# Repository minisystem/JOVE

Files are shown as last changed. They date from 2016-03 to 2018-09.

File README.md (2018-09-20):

SYSTEM80 JOVE Multimode Filter
============

Roland Jupiter 6 inspired multimode filter in 14HP Eurorack format. IR3109s replaced with LM13700 OTAs.
Selectable 24 dB low pass, bonus 2 pole 12 dB low pass, band pass and high pass modes.

Product page: http://system80.net/product/jove/<br>

Demos:<br>
https://soundcloud.com/system_80/sets/jove-demo<br>
https://soundcloud.com/system_80/sets/jove-mimoid-demo<br>
https://www.youtube.com/watch?v=VFNtQRDSUw4

EDA files generated in KiCad 4.0.2. Schematic library here: https://github.com/minisystem/MyKicadLibraries/blob/master/MySynthParts.lib
KiCad GitHub libraries required as well. :/
Front panel design by Bartek Kawula.<br>
Hardware design by minisystem: info@system80.net

PCB
===
See /Gerbers/JOVE-gerbers-1.6.zip

BOM
===
Octopart BOM: https://octopart.com/bom-tool/0BVEzM8i<br>
NOTE 1: R66 and R67 can be 0805 10R resistors or PTC fuses (see BOM for part number)<br>
NOTE 2: C1, C11, C28, C29 can be either 10 pF or 22 pF<br>

CALIBRATION
===========
Feed one of the inputs a 10 Vpp ~50 Hz square wave. In 12 dB mode with frequency and resonance knobs both at minimum (fully CCW), adjust VR5 so that the filter is fully closed. This is best done by ear using headphones. Then switch to HP mode with frequency knob at max (fully CW) and listen to ensure most of the high frequency harmonics are gone. There's a sweet spot where maximum attenuation in both modes can be achieved. The resonance trimmer is used to ensure that there is minimum resonance when the resonance knob is fully CCW. Set the frequency knob at about 12 o'clock and look for a resonance peak on the square wave in 12 dB mode using an oscilloscope. Adjust the input gain so that the output square wave is 10 Vpp. Then use VR7 to to trim away the resonance peak so that the square wave is flat. 

Acknowledgements
================
The idea to hybridize the audio input and control voltage stages from the MKS80 and SH101, respectively, comes directly from
the AMSynths AM8060: http://www.amsynthstore.co.uk/

LICENSE
=======
cc-by-nc-sa
https://creativecommons.org/licenses/by-nc-sa/4.0/<br><br>
Please note the NON-COMMERCIAL (NC) clause of the Creative Commons license.  You do not have permission to build and sell JOVE for monetary compensation.
Make one for yourself, make an extra and sell it to your friend? That's cool. Make several and sell them on eBay/ModularGrid/Tindie? No, don't do that! :)<br><br>
The NC clause isn't going to be around forever and eventually derative works for commercial use will be allowed, but currently commerical use is prohibited by the license. <br><br>
Please also note the ShareAlike (SA) clause of the license: if you create a derivative work, please ensure that it is distributed under the same license and is not used commercially.

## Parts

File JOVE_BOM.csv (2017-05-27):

Qty | Line Item | Manufacturer | MPN | Octopart URL | Schematic Reference | Internal Part Number | Description | Total Qty (@ Batch Size: 1) | SKU | SKU | Packaging | Packaging | Unit Price (@ Batch Size: 1) | Unit Price (@ Batch Size: 1) | In Stock | In Stock | MOQ | MOQ | URL | URL | Distributor [Lowest Price (Overall)] | SKU [Lowest Price (Overall)] | Packaging [Lowest Price (Overall)] | Unit Price (@ Batch Size: 1) [Lowest Price (Overall)] | Line Total [Lowest Price (Overall)] | Batch Total [Lowest Price (Overall)] | In Stock [Lowest Price (Overall)] | MOQ [Lowest Price (Overall)] | URL [Lowest Price (Overall)] | Notes
 |  |  |  |  |  |  |  |  | Digi-Key | Mouser | Digi-Key | Mouser | Digi-Key | Mouser | Digi-Key | Mouser | Digi-Key | Mouser | Digi-Key | Mouser
2 | C0603C470J5GACTU | KEMET | C0603C470J5GACTU | https://octopart.com/c0603c470j5gactu-kemet-96565 | C5,C2 | 47pF | 0603 | 2 | 399-1056-1-ND | C0603C470J5GACTU | Cut Tape |  | 0.134505 | 0.134505 | 470434 | 116632 | 1 |  | https://octopart.com/click/track?country=CA&ak=68b25f31&sig=0e3ff3a&sid=459&ppid=96565&vpid=1141107&ct=offers | https://octopart.com/click/track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 | Quest | C0603C470J5GACTU |  | 0.0403515 | 0.080703 | 0.080703 | 106700 |  | https://octopart.com/click/track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
4 | PFR5331J100J11L4BULK | KEMET | PFR5331J100J11L4BULK | https://octopart.com/pfr5331j100j11l4bulk-kemet-20374205 | C6,C7,C18,C25 | 330p FILM | 5 MM BOX CAP | 4 | 399-7719-ND | PFR5331J100J11L4BULK | Bulk |  | 0.7666784999999999 | 0.7666784999999999 | 629 | 790 | 1 |  | https://octopart.com/click/track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 | https://octopart.com/click/track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 | Digi-Key | 399-7719-ND | Bulk | 0.7666784999999999 | 3.0667139999999997 | 3.0667139999999997 | 629 | 1 | https://octopart.com/click/track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
2 | CC0603CRNPO9BN4R7 | Yageo | CC0603CRNPO9BN4R7 | https://octopart.com/cc0603crnpo9bn4r7-yageo-41162001 | C8,C3 | 4.7pF | 0603 | 2 | 311-1740-1-ND | CC0603CRNPO9BN4R7 | Cut Tape |  | 0.134505 | 0.134505 | 53904 | 2742 | 1 |  | https://octopart.com/click/track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 | https://octopart.com/click/track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 | Future Electronics | 4871679 | Cut Tape | 0.0043041600000000005 | 0.008608320000000001 | 0.008608320000000001 | 0 | 1 | https://octopart.com/click/track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
2 | C0603C330J5GACTU | KEMET | C0603C330J5GACTU | https://octopart.com/c0603c330j5gactu-kemet-87666 | C9,C4 | 33pF | 0603 | 2 | 399-1055-1-ND | C0603C330J5GACTU | Cut Tape |  | 0.134505 | 0.134505 | 159937 | 66424 | 1 |  | https://octopart.com/click/track?country=CA&ak=68b25f31&sig=03ed878&sid=459&ppid=87666&vpid=1868169&ct=offers | https://octopart.com/click/track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 | Quest | C0603C330J5GACTU |  | 0.04438665000000001 | 0.08877330000000001 | 0.08877330000000001 | 87384 |  | https://octopart.com/click/track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
1 | UUQ1E100MCL1GB | Nichicon | UUQ1E100MCL1GB | https://octopart.com/uuq1e100mcl1gb-nichicon-19038212 | C10 | 10μF | 5mm x 5.3mm | 1 | 493-3202-1-ND | UUQ1E100MCL1GB | Cut Tape |  | 0.6590745 | 0.6052725000000001 | 436 | 1420 | 1 |  | https://octopart.com/click/track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 | https://octopart.com/click/track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 | Arrow | UUQ1E100MCL1GB**MULT1 | Cut Tape | 0.44184892500000006 | 0.44184892500000006 | 0.44184892500000006 | 190 | 1 | https://octopart.com/click/track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
4 | C0603C100J5GACTU | KEMET | C0603C100J5GACTU | https://octopart.com/c0603c100j5gactu-kemet-138281 | C11,C1,C28,C29 | 22pF | 0603 | 4 | 399-1049-1-ND | C0603C100J5GACTU | Cut Tape |  | 0.134505 | 0.134505 | 684636 | 136314 | 1 |  | https://octopart.com/click/track?country=CA&ak=68b25f31&sig=0221e5b&sid=459&ppid=138281&vpid=2013189&ct=offers | https://octopart.com/click/track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 | Quest | C0603C100J5GACTU |  | 0.04438665000000001 | 0.17754660000000003 | 0.17754660000000003 | 90266 |  | https://octopart.com/click/track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
2 | GRM188R61E105KA12D | Murata | GRM188R61E105KA12D | https://octopart.com/grm188r61e105ka12d-murata-197449 | C22,C21 | 1μ | 0603 | 2 | 490-3897-1-ND | GRM188R61E105KA12D | Cut Tape |  | 0.134505 | 0.14795550000000002 | 2332690 | 474291 | 1 |  | https://octopart.com/click/track?country=CA&ak=68b25f31&sig=0dbf803&sid=459&ppid=197449&vpid=1620758&ct=offers | https://octopart.com/click/track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 | Arrow | GRM188R61E105KA12D**MULT |  | 0.058375170000000004 | 0.11675034000000001 | 0.11675034000000001 | 104 | 1 | https://octopart.com/click/track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
2 | EEE-1EA100SR | Panasonic | EEE1EA100SR | https://octopart.com/eee1ea100sr-panasonic-55403445 | C23,C24 | 10μF | 5mm x 5.8mm | 2 | PCE3894CT-ND | EEE1EA100SR | Cut Tape |  | 0.44386650000000005 | 0.48421800000000004 | 119898 | 4880 | 1 |  | https://octopart.com/click/track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 | https://octopart.com/click/track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 | Allied Electronics | 70257957 | Bulk | 0.10087875 | 0.2017575 | 0.2017575 | 1445 | 1 | https://octopart.com/click/track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
10 | C0603C104M5RACTU | KEMET | C0603C104M5RACTU | https://octopart.com/c0603c104m5ractu-kemet-11855687 | C27,C20,C19,C17,C16,C15,C14,C13,C12,C26 | 100n | 0603 | 10 | 399-7845-1-ND | C0603C104M5RACTU | Cut Tape |  | 0.039006450000000005 | 0.021520800000000003 | 2577395 | 477739 | 1 |  | https://octopart.com/click/track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 | https://octopart.com/click/track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 | Mouser | C0603C104M5RACTU |  | 0.021520800000000003 | 0.21520800000000004 | 0.21520800000000004 | 477739 |  | https://octopart.com/click/track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
4 | WP424SRDT | Kingbright | WP424SRDT | https://octopart.com/wp424srdt-kingbright-5355810 | D1,D2,D3,D4 | LED | 3 MM LED | 4 | 754-1717-ND | WP424SRDT | Bulk |  | 0.6590745 | 0.34971300000000005 | 9014 | 1900 | 1 |  | https://octopart.com/click/track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 | https://octopart.com/click/track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 | Mouser | WP424SRDT |  | 0.34971300000000005 | 1.3988520000000002 | 1.3988520000000002 | 1900 |  | https://octopart.com/click/track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
2 | S1BB-13-F | Diodes Inc. | S1BB-13-F | https://octopart.com/s1bb-13-f-diodes+inc.-333220 | D8,D9 | S1BB | SMB | 2 | S1BB-FDICT-ND | S1BB-13-F | Cut Tape |  | 0.4976685 | 0.564921 | 32572 | 4740 | 1 |  | https://octopart.com/click/track?country=CA&ak=68b25f31&sig=04f214c&sid=459&ppid=333220&vpid=1137864&ct=offers | https://octopart.com/click/track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 | Freelance Electronics | S1BB-13-F |  | 0.12105450000000001 | 0.24210900000000002 | 0.24210900000000002 | 3000 |  | https://octopart.com/click/track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
4 | 1N914BWS | Fairchild Semiconductor | 1N914BWS | https://octopart.com/1n914bws-fairchild+semiconductor-7850921 | D10,D7,D6,D5 | 1N914 | SOD323 | 4 | 1N914BWSCT-ND | 1N914BWS | Cut Tape |  | 0.18830700000000003 | 0.17485650000000003 | 253227 | 61488 | 1 |  | https://octopart.com/click/track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 | https://octopart.com/click/track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 | Rochester Electronics | 1N914BWS |  | 0.026901 | 0.107604 | 0.107604 | 70048 |  | https://octopart.com/click/track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
6 | PJ301BM |  |  |  | J1,J2,J3,J4,J5,J6 | WQP-PJ301BM | 3.5 MM JACK | 6
2 | BCM857BS-7-F | Diodes Inc. | BCM857BS-7-F | https://octopart.com/bcm857bs-7-f-diodes+inc.-67250368 | Q2,Q1 | BCM857BS | SOT323-6 | 2 | BCM857BS-7-FDICT-ND | BCM857BS-7-F | Cut Tape |  | 0.44386650000000005 | 0.403515 | 950 | 2760 | 1 |  | https://octopart.com/click/track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 | https://octopart.com/click/track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 | Mouser | BCM857BS-7-F |  | 0.403515 | 0.80703 | 0.80703 | 2760 |  | https://octopart.com/click/track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
4 | MMBFJ112 | Fairchild Semiconductor | MMBFJ112 | https://octopart.com/mmbfj112-fairchild+semiconductor-13412317 | Q6,Q5,Q4,Q3 | J112 | SOT23 | 4 | MMBFJ112CT-ND |  | Cut Tape |  | 0.618723 |  | 14344 |  | 1 |  | https://octopart.com/click/track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 |  | Future Electronics | 3286895 | Cut Tape | 0.1129842 | 0.4519368 | 0.4519368 | 0 | 1 | https://octopart.com/click/track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
4 | RC0603FR-0710KL | Yageo | RC0603FR-0710KL | https://octopart.com/rc0603fr-0710kl-yageo-40025538 | R1,R49,R70,R71 | 10K | 0603 | 4 | 311-10.0KHRCT-ND | RC0603FR-0710KL | Cut Tape |  | 0.134505 | 0.134505 | 17944628 | 1019470 | 1 |  | https://octopart.com/click/track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 | https://octopart.com/click/track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 | Area51 | RC0603FR-0710KL |  | 0.002017575 | 0.0080703 | 0.0080703 | 5385 |  | https://octopart.com/click/track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
2 | RC0603FR-07200KL | Yageo | RC0603FR-07200KL | https://octopart.com/rc0603fr-07200kl-yageo-1190520 | R5,R6 | 200K | 0603 | 2 | 311-200KHRCT-ND | RC0603FR-07200KL | Cut Tape |  | 0.134505 | 0.134505 | 1134443 | 108759 | 1 |  | https://octopart.com/click/track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 | https://octopart.com/click/track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 | Freelance Electronics | RC0603FR-07200KL |  | 0.0134505 | 0.026901 | 0.026901 | 0 |  | https://octopart.com/click/track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
1 | RC0603FR-07110KL | Yageo | RC0603FR-07110KL | https://octopart.com/rc0603fr-07110kl-yageo-1180242 | R9 | 110K | 0603 | 1 | 311-110KHRCT-ND | RC0603FR-07110KL | Cut Tape |  | 0.134505 | 0.134505 | 508755 | 129823 | 1 |  | https://octopart.com/click/track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 | https://octopart.com/click/track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 | Quest | RC0603FR-07110KL |  | 0.018158175000000002 | 0.018158175000000002 | 0.018158175000000002 | 4905 |  | https://octopart.com/click/track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
1 | RC0603FR-07680KL | Yageo | RC0603FR-07680KL | https://octopart.com/rc0603fr-07680kl-yageo-55458494 | R10 | 680K | 0603 | 1 | 311-680KHRCT-ND | RC0603FR-07680KL | Cut Tape |  | 0.134505 | 0.134505 | 235274 | 34193 | 1 |  | https://octopart.com/click/track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 | https://octopart.com/click/track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 | Newark | 66R2539 |  | 0.008 | 0.008 | 0.008 | 0 |  | https://octopart.com/click/track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
1 | RC0603FR-071ML | Yageo | RC0603FR-071ML | https://octopart.com/rc0603fr-071ml-yageo-1168402 | R11 | 1M | 0603 | 1 | 311-1.00MHRCT-ND | RC0603FR-071ML | Cut Tape |  | 0.134505 | 0.134505 | 2247161 | 602974 | 1 |  | https://octopart.com/click/track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 | https://octopart.com/click/track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 | Quest | RC0603FR-071ML |  | 0.018158175000000002 | 0.018158175000000002 | 0.018158175000000002 | 73887 |  | https://octopart.com/click/track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
2 | RC0603FR-071KL | Yageo | RC0603FR-071KL | https://octopart.com/rc0603fr-071kl-yageo-55402882 | R12,R54 | 1K | 0603 | 2 | 311-1.00KHRCT-ND | RC0603FR-071KL | Cut Tape |  | 0.134505 | 0.134505 | 7245403 | 1109725 | 1 |  | https://octopart.com/click/track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 | https://octopart.com/click/track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 | Area51 | RC0603FR-071KL |  | 0.0026901000000000004 | 0.005380200000000001 | 0.005380200000000001 | 15094 |  | https://octopart.com/click/track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
4 | RC0603FR-071KL | Yageo | RC0603FR-071KL | https://octopart.com/rc0603fr-071kl-yageo-55402882 | R13,R14,R18,R50 | 47K | 0603 | 4 | 311-1.00KHRCT-ND | RC0603FR-071KL | Cut Tape |  | 0.134505 | 0.134505 | 7245403 | 1109725 | 1 |  | https://octopart.com/click/track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 | https://octopart.com/click/track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 | Area51 | RC0603FR-071KL |  | 0.0026901000000000004 | 0.010760400000000002 | 0.010760400000000002 | 15094 |  | https://octopart.com/click/track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
1 | RC0603FR-07150KL | Yageo | RC0603FR-07150KL | https://octopart.com/rc0603fr-07150kl-yageo-40301068 | R15 | 150K | 0603 | 1 | 311-150KHRCT-ND | RC0603FR-07150KL | Cut Tape |  | 0.134505 | 0.134505 | 397717 | 170321 | 1 |  | https://octopart.com/click/track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 | https://octopart.com/click/track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 | Quest | RC0603FR-07150KL |  | 0.0242109 | 0.0242109 | 0.0242109 | 27642 |  | https://octopart.com/click/track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
1 | RC0603FR-074K7L | Yageo | RC0603FR-074K7L | https://octopart.com/rc0603fr-074k7l-yageo-55402884 | R16 | 4.7K | 0603 | 1 | 311-4.70KHRCT-ND | RC0603FR-074K7L | Cut Tape |  | 0.134505 | 0.134505 | 3399606 | 646715 | 1 |  | https://octopart.com/click/track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 | https://octopart.com/click/track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 | Area51 | RC0603FR-074K7L |  | 0.0029591100000000005 | 0.0029591100000000005 | 0.0029591100000000005 | 14451 |  | https://octopart.com/click/track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
1 | RC0603FR-105K6L | Yageo | RC0603FR-105K6L | https://octopart.com/rc0603fr-105k6l-yageo-16255932 | R17 | 5.6K | 0603 | 1 |  | RC0603FR-105K6L |  |  |  | 0.134505 |  | 68551 |  |  |  | https://octopart.com/click/track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 | Mouser | RC0603FR-105K6L |  | 0.134505 | 0.134505 | 0.134505 | 68551 |  | https://octopart.com/click/track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
1 | ABNTC-0805-103J-3950F-T | Abracon | ABNTC-0805-103J-3950F-T | https://octopart.com/abntc-0805-103j-3950f-t-abracon-29811145 | R19 | 10K NTC | 0805 | 1 | 535-12852-1-ND |  | Cut Tape |  | 0.36316350000000003 |  | 2579 |  | 1 |  | https://octopart.com/click/track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 |  | Digi-Key | 535-12852-1-ND | Cut Tape | 0.36316350000000003 | 0.36316350000000003 | 0.36316350000000003 | 2579 | 1 | https://octopart.com/click/track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
2 | RC0603FR-071K5L | Yageo | RC0603FR-071K5L | https://octopart.com/rc0603fr-071k5l-yageo-55458478 | R20,R27 | 1.5K | 0603 | 2 | 311-1.50KHRCT-ND | RC0603FR-071K5L | Cut Tape |  | 0.134505 | 0.134505 | 454711 | 216796 | 1 |  | https://octopart.com/click/track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 | https://octopart.com/click/track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 | Area51 | RC0603FR-071K5L |  | 0.0026901000000000004 | 0.005380200000000001 | 0.005380200000000001 | 2299 |  | https://octopart.com/click/track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
2 | RC0603FR-071M5L | Yageo | RC0603FR-071M5L | https://octopart.com/rc0603fr-071m5l-yageo-40315640 | R21,R28 | 1.5M | 0603 | 2 | 311-1.50MHRCT-ND | RC0603FR-071M5L | Cut Tape |  | 0.134505 | 0.134505 | 306867 | 0 | 1 |  | https://octopart.com/click/track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 | https://octopart.com/click/track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 | Future Electronics | 6843296 | Cut Tape | 0.07397775000000001 | 0.14795550000000002 | 0.14795550000000002 | 0 | 1 | https://octopart.com/click/track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
1 | RC0603FR-078K2L | Yageo | RC0603FR-078K2L | https://octopart.com/rc0603fr-078k2l-yageo-40301092 | R22 | 8.2K | 0603 | 1 | 311-8.20KHRCT-ND | RC0603FR-078K2L | Cut Tape |  | 0.134505 | 0.134505 | 668000 | 60464 | 1 |  | https://octopart.com/click/track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 | https://octopart.com/click/track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 | Quest | RC0603FR-078K2L |  | 0.018158175000000002 | 0.018158175000000002 | 0.018158175000000002 | 53805 |  | https://octopart.com/click/track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
1 | RC0603FR-071K8L | Yageo | RC0603FR-071K8L | https://octopart.com/rc0603fr-071k8l-yageo-40952851 | R23 | 1.8K | 0603 | 1 | 311-1.80KHRCT-ND | RC0603FR-071K8L | Cut Tape |  | 0.134505 | 0.134505 | 435112 | 113375 | 1 |  | https://octopart.com/click/track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 | https://octopart.com/click/track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 | Quest | RC0603FR-071K8L |  | 0.018158175000000002 | 0.018158175000000002 | 0.018158175000000002 | 3171 |  | https://octopart.com/click/track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
1 | RC0603FR-07820RL | Yageo | RC0603FR-07820RL | https://octopart.com/rc0603fr-07820rl-yageo-41204300 | R25 | 820 | 0603 | 1 | 311-820HRCT-ND | RC0603FR-07820RL | Cut Tape |  | 0.134505 | 0.134505 | 216811 | 16295 | 1 |  | https://octopart.com/click/track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 | https://octopart.com/click/track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 | Future Electronics | 8386369 | Cut Tape | 0.07397775000000001 | 0.07397775000000001 | 0.07397775000000001 | 2703 | 1 | https://octopart.com/click/track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
6 | RC0603FR-0768KL | Yageo | RC0603FR-0768KL | https://octopart.com/rc0603fr-0768kl-yageo-41204191 | R29,R35,R37,R52,R60,R63 | 68K | 0603 | 6 | 311-68.0KHRCT-ND | RC0603FR-0768KL | Cut Tape |  | 0.134505 | 0.134505 | 613756 | 73519 | 1 |  | https://octopart.com/click/track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 | https://octopart.com/click/track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 | ExcessParts.Net | RC0603FR-0768KL |  | 0.0134505 | 0.080703 | 0.080703 | 4967 |  | https://octopart.com/click/track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
6 | RC0603FR-07560RL | Yageo | RC0603FR-07560RL | https://octopart.com/rc0603fr-07560rl-yageo-1265587 | R30,R36,R38,R53,R62,R65 | 560 | 0603 | 6 | 311-560HRCT-ND | RC0603FR-07560RL | Cut Tape |  | 0.134505 | 0.134505 | 1093994 | 48486 | 1 |  | https://octopart.com/click/track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 | https://octopart.com/click/track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 | Quest | RC0603FR-07560RL |  | 0.030263625000000002 | 0.18158175000000001 | 0.18158175000000001 | 4730 |  | https://octopart.com/click/track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
6 | RC0603FR-0718KL | Yageo | RC0603FR-0718KL | https://octopart.com/rc0603fr-0718kl-yageo-40952836 | R31,R32,R39,R55,R56,R68 | 18K | 0603 | 6 | 311-18.0KHRCT-ND | RC0603FR-0718KL | Cut Tape |  | 0.134505 | 0.134505 | 574517 | 68400 | 1 |  | https://octopart.com/click/track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 | https://octopart.com/click/track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 | Future Electronics | 7908486 | Cut Tape | 0.07397775000000001 | 0.44386650000000005 | 0.44386650000000005 | 0 | 1 | https://octopart.com/click/track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
7 | RC0603FR-0733KL | Yageo | RC0603FR-0733KL | https://octopart.com/rc0603fr-0733kl-yageo-40254901 | R33,R34,R40,R46,R57,R58,R69 | 33K | 0603 | 7 | 311-33.0KHRCT-ND | RC0603FR-0733KL | Cut Tape |  | 0.134505 | 0.134505 | 603894 | 372069 | 1 |  | https://octopart.com/click/track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 | https://octopart.com/click/track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 | Newark | 68R0084 | Cut Tape | 0.002 | 0.014 | 0.014 | 3250 | 1 | https://octopart.com/click/track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
1 | RC0603FR-073K3L | Yageo | RC0603FR-073K3L | https://octopart.com/rc0603fr-073k3l-yageo-40011875 | R41 | 3.3K | 0603 | 1 | 311-3.30KHRCT-ND | RC0603FR-073K3L | Cut Tape |  | 0.134505 | 0.134505 | 1860756 | 206098 | 1 |  | https://octopart.com/click/track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 | https://octopart.com/click/track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 | Quest | RC0603FR-073K3L |  | 0.0242109 | 0.0242109 | 0.0242109 | 29387 |  | https://octopart.com/click/track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
2 | RC0603FR-0756KL | Yageo | RC0603FR-0756KL | https://octopart.com/rc0603fr-0756kl-yageo-41455254 | R42,R43 | 56K | 0603 | 2 | 311-56KHRCT-ND | RC0603FR-0756KL | Cut Tape |  | 0.134505 | 0.134505 | 434712 | 130124 | 1 |  | https://octopart.com/click/track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 | https://octopart.com/click/track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 | Digi-Key | 311-56KHRCT-ND | Cut Tape | 0.134505 | 0.26901 | 0.26901 | 434712 | 1 | https://octopart.com/click/track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
1 | RC0603FR-07330KL | Yageo | RC0603FR-07330KL | https://octopart.com/rc0603fr-07330kl-yageo-40952887 | R51 | 330K | 0603 | 1 | 311-330KHRCT-ND | RC0603FR-07330KL | Cut Tape |  | 0.134505 | 0.134505 | 232278 | 41774 | 1 |  | https://octopart.com/click/track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 | https://octopart.com/click/track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 | ExcessParts.Net | RC0603FR-07330KL |  | 0.0134505 | 0.0134505 | 0.0134505 | 4979 |  | https://octopart.com/click/track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
2 | RC0603FR-07330RL | Yageo | RC0603FR-07330RL | https://octopart.com/rc0603fr-07330rl-yageo-40301083 | R59,R64 | 330 | 0603 | 2 | 311-330HRCT-ND | RC0603FR-07330RL | Cut Tape |  | 0.134505 | 0.134505 | 1445260 | 68556 | 1 |  | https://octopart.com/click/track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 | https://octopart.com/click/track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 | Quest | RC0603FR-07330RL |  | 0.0242109 | 0.0484218 | 0.0484218 | 21201 |  | https://octopart.com/click/track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
2 | ERJ-8GEYJ100V | Panasonic | ERJ-8GEYJ100V | https://octopart.com/erj-8geyj100v-panasonic-55423812 | R67,R66 | 10 | 0805 | 2 | P10ECT-ND | ERJ-8GEYJ100V | Cut Tape |  | 0.134505 | 0.134505 | 490916 | 28966 | 1 |  | https://octopart.com/click/track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 | https://octopart.com/click/track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 | Allied Electronics | 70266197 | Bulk | 0.00403515 | 0.0080703 | 0.0080703 | 143780 | 1 | https://octopart.com/click/track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
1 | RC0603FR-07270KL | Yageo | RC0603FR-07270KL | https://octopart.com/rc0603fr-07270kl-yageo-40301078 | R72 | 270K | 0603 | 1 | 311-270KHRCT-ND | RC0603FR-07270KL | Cut Tape |  | 0.134505 | 0.134505 | 664816 | 81941 | 1 |  | https://octopart.com/click/track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 | https://octopart.com/click/track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 | Area51 | RC0603FR-07270KL |  | 0.003362625 | 0.003362625 | 0.003362625 | 9615 |  | https://octopart.com/click/track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
19 | RC0603FR-07100KL | Yageo | RC0603FR-07100KL | https://octopart.com/rc0603fr-07100kl-yageo-40946036 | R76,R2,R3,R4,R7,R8,R24,R26,R44,R45,R47,R48,R61,R73,R74,R75,R77,R78 | 100K | 0603 | 19 | 311-100KHRCT-ND | RC0603FR-07100KL | Cut Tape |  | 0.018830700000000002 | 0.0134505 | 4853686 | 967388 | 1 |  | https://octopart.com/click/track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 | https://octopart.com/click/track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 | Farnell | 9238727 | Cut Tape | 0.012229073880094352 | 0.23235240372179267 | 0.23235240372179267 | 129026 | 10 | https://octopart.com/click/track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
1 | KS-01Q-01 | E-Switch | KS-01Q-01 | https://octopart.com/ks-01q-01-e-switch-18183226 | SW1 | SWITCH | KS-01Q | 1 | EG4791-ND | KS-01Q-01 | Bulk |  | 0.7128765 | 0.6994260000000001 | 7502 | 3773 | 1 |  | https://octopart.com/click/track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 | https://octopart.com/click/track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 | Straight Road Electronics | KS-01Q-01 |  | 0.5245695 | 0.5245695 | 0.5245695 | 0 |  | https://octopart.com/click/track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
4 | TL072CPWR | Texas Instruments | TL072CPWR | https://octopart.com/tl072cpwr-texas+instruments-409969 | U1,U2,U3,U4 | TL072 | TSSOP8 | 4 | 296-7193-1-ND | TL072CPWR | Cut Tape |  | 0.8339310000000001 | 0.7935795 | 13222 | 8545 | 1 |  | https://octopart.com/click/track?country=CA&ak=68b25f31&sig=07aa9a4&sid=459&ppid=409969&vpid=1542372&ct=offers | https://octopart.com/click/track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 | Rochester Electronics | TL072CPWR |  | 0.3900645 | 1.560258 | 1.560258 | 4890 |  | https://octopart.com/click/track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

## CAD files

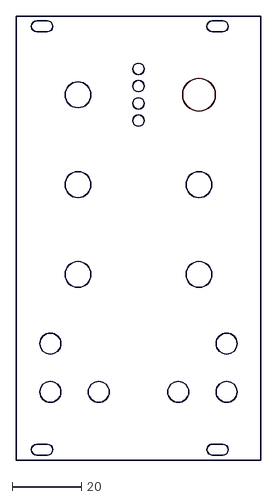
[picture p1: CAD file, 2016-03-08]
Panel/Jove_panel_drill_holes.dxf
70.8 x 128.5

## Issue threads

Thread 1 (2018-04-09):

Value for c1 c11 c28 and c29

pandereteiro, 2018-04-09:
Schematics call for 22pF

BOM (row #8) calls for 10pF https://github.com/minisystem/JOVE/blob/master/JOVE_BOM.csv
even pointing to this in Octopart: https://octopart.com/c0603c100j5gactu-kemet-138281

Which is the correct value for those capacitors?

fabianunterstell, 2020-07-25:
from the README.md:
NOTE 2: C1, C11, C28, C29 can be either 10 pF or 22 pF

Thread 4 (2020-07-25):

resistors r67, r66 with wrong smd package size in the BOM

fabianunterstell, 2020-07-25:
in the BOM the resistors r67, r66 have package size 0805 in the description field and that size fits on the pcb as well.

the recommended resistor is a panasonic ERJ-8GEYJ100V which has package size 1206 as can be seen in the datasheet here:
https://www.mouser.de/datasheet/2/315/AOA0000C301-1488782.pdf

the correct sized resistor would be the panasonic ERJ-6GEYJ100V

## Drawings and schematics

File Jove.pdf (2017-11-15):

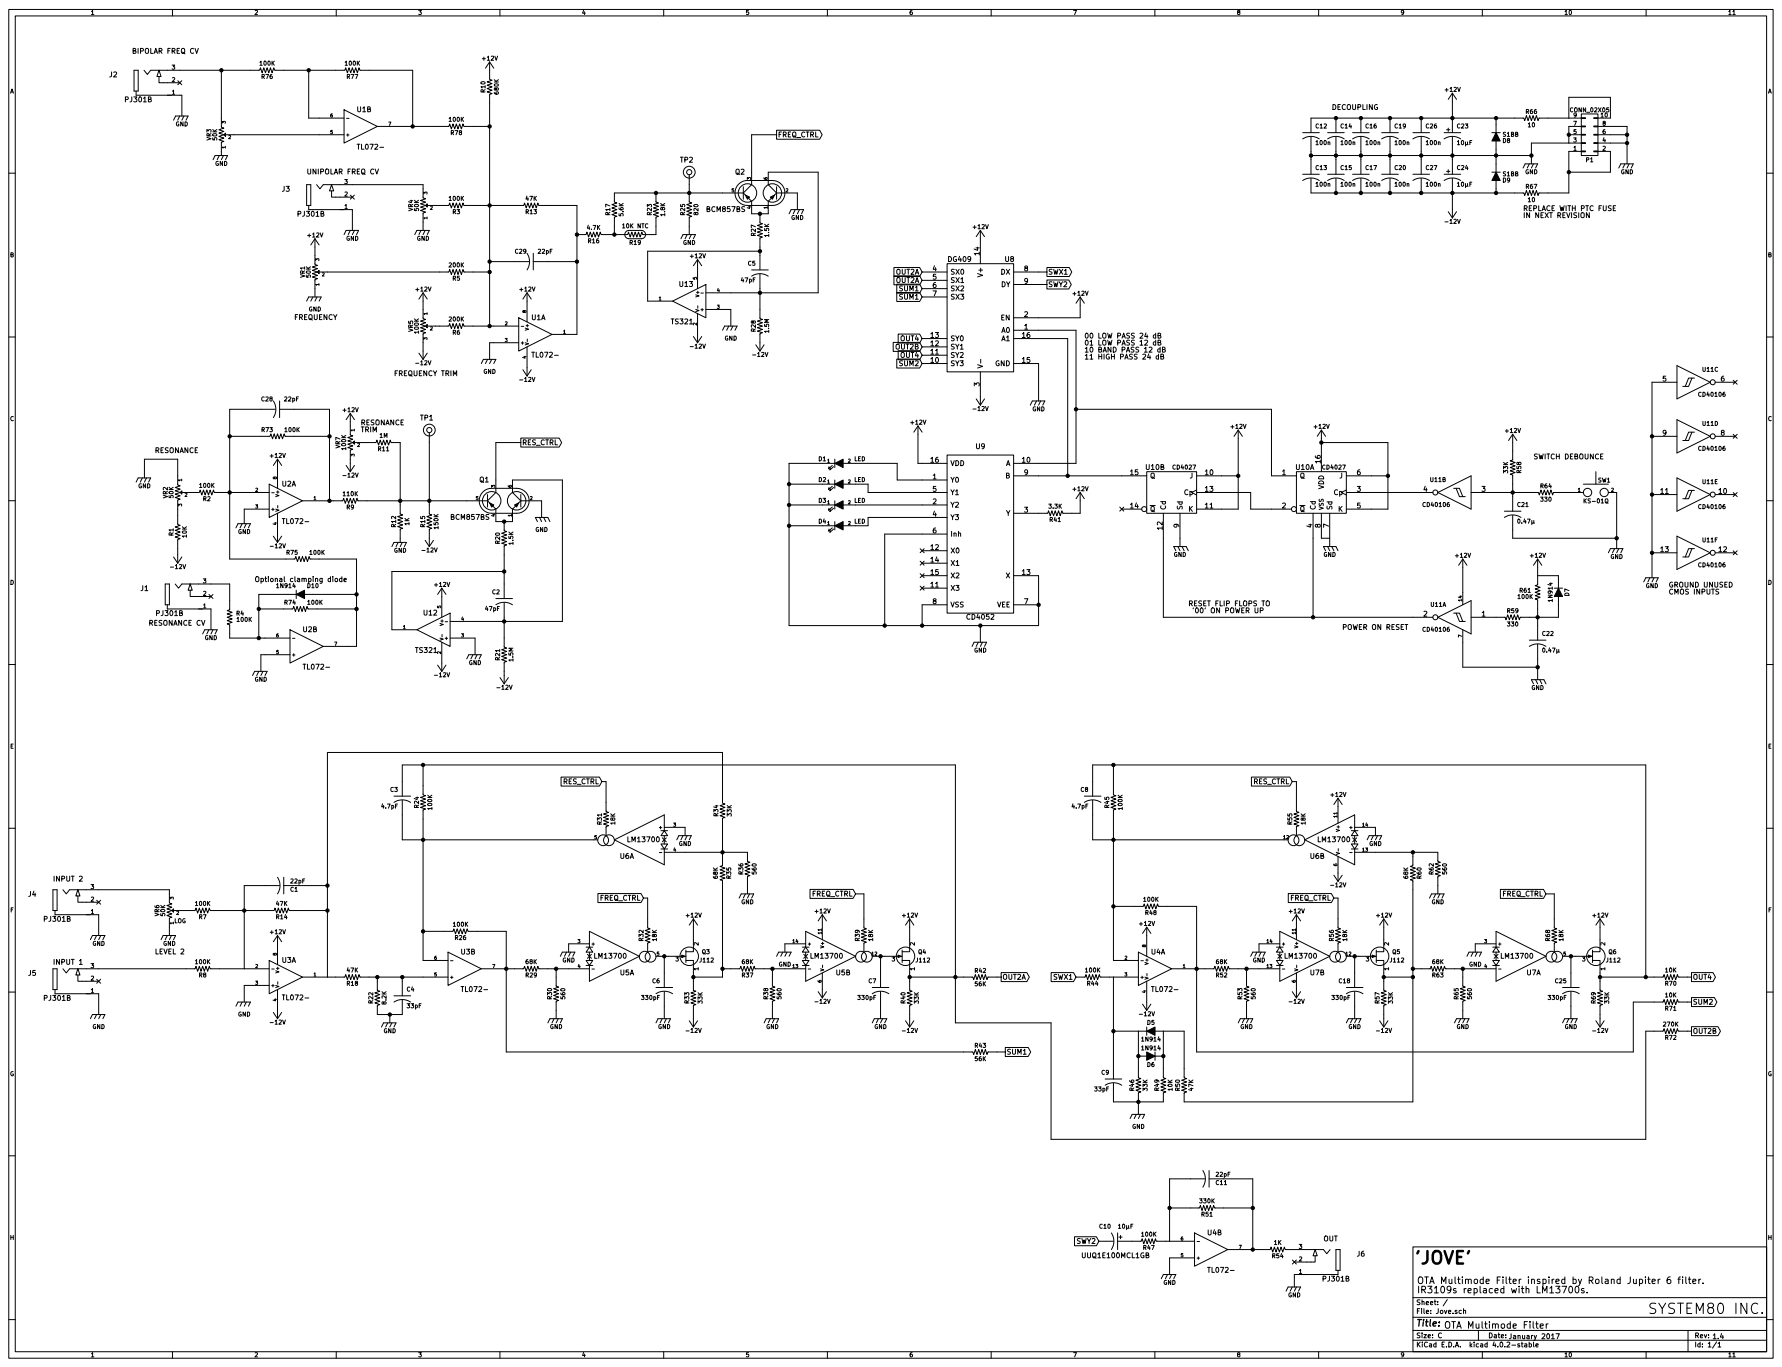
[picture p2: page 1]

REPLACE WITH PTC FUSE
IN NEXT REVISION

CMOS INPUTS RESET FLIP FLOPS TO

OTA Multimode Filter inspired by Roland Jupiter 6 filter.

Id: 1/1 Title: File: Jove.sch Sheet: /

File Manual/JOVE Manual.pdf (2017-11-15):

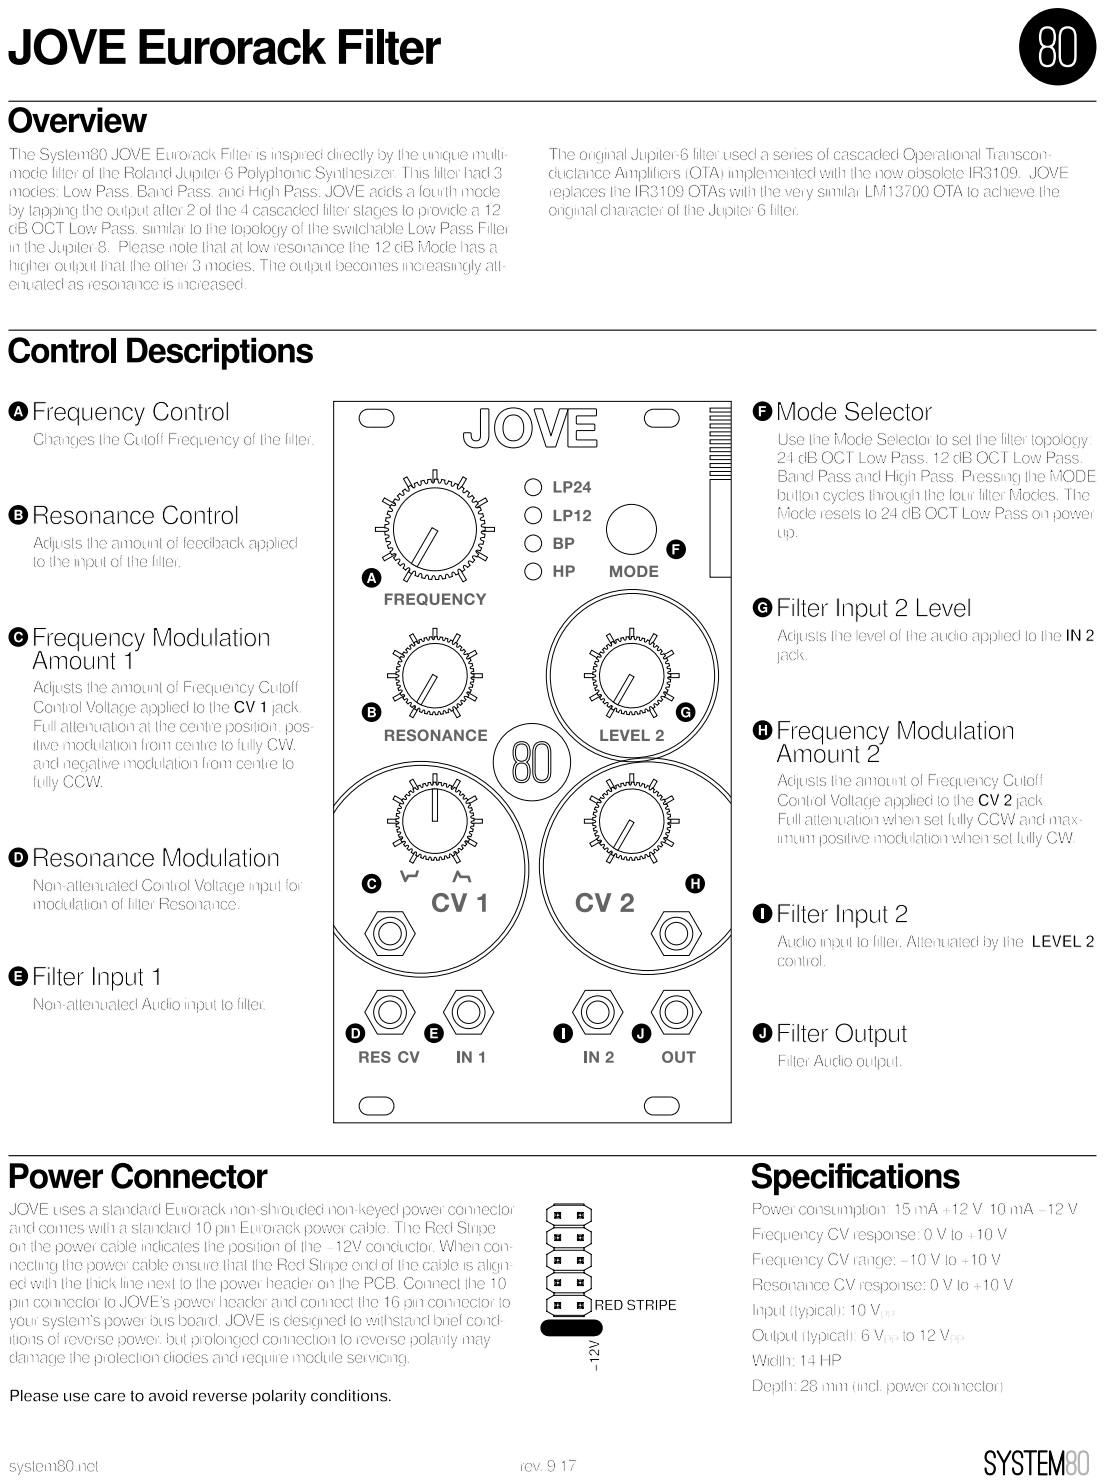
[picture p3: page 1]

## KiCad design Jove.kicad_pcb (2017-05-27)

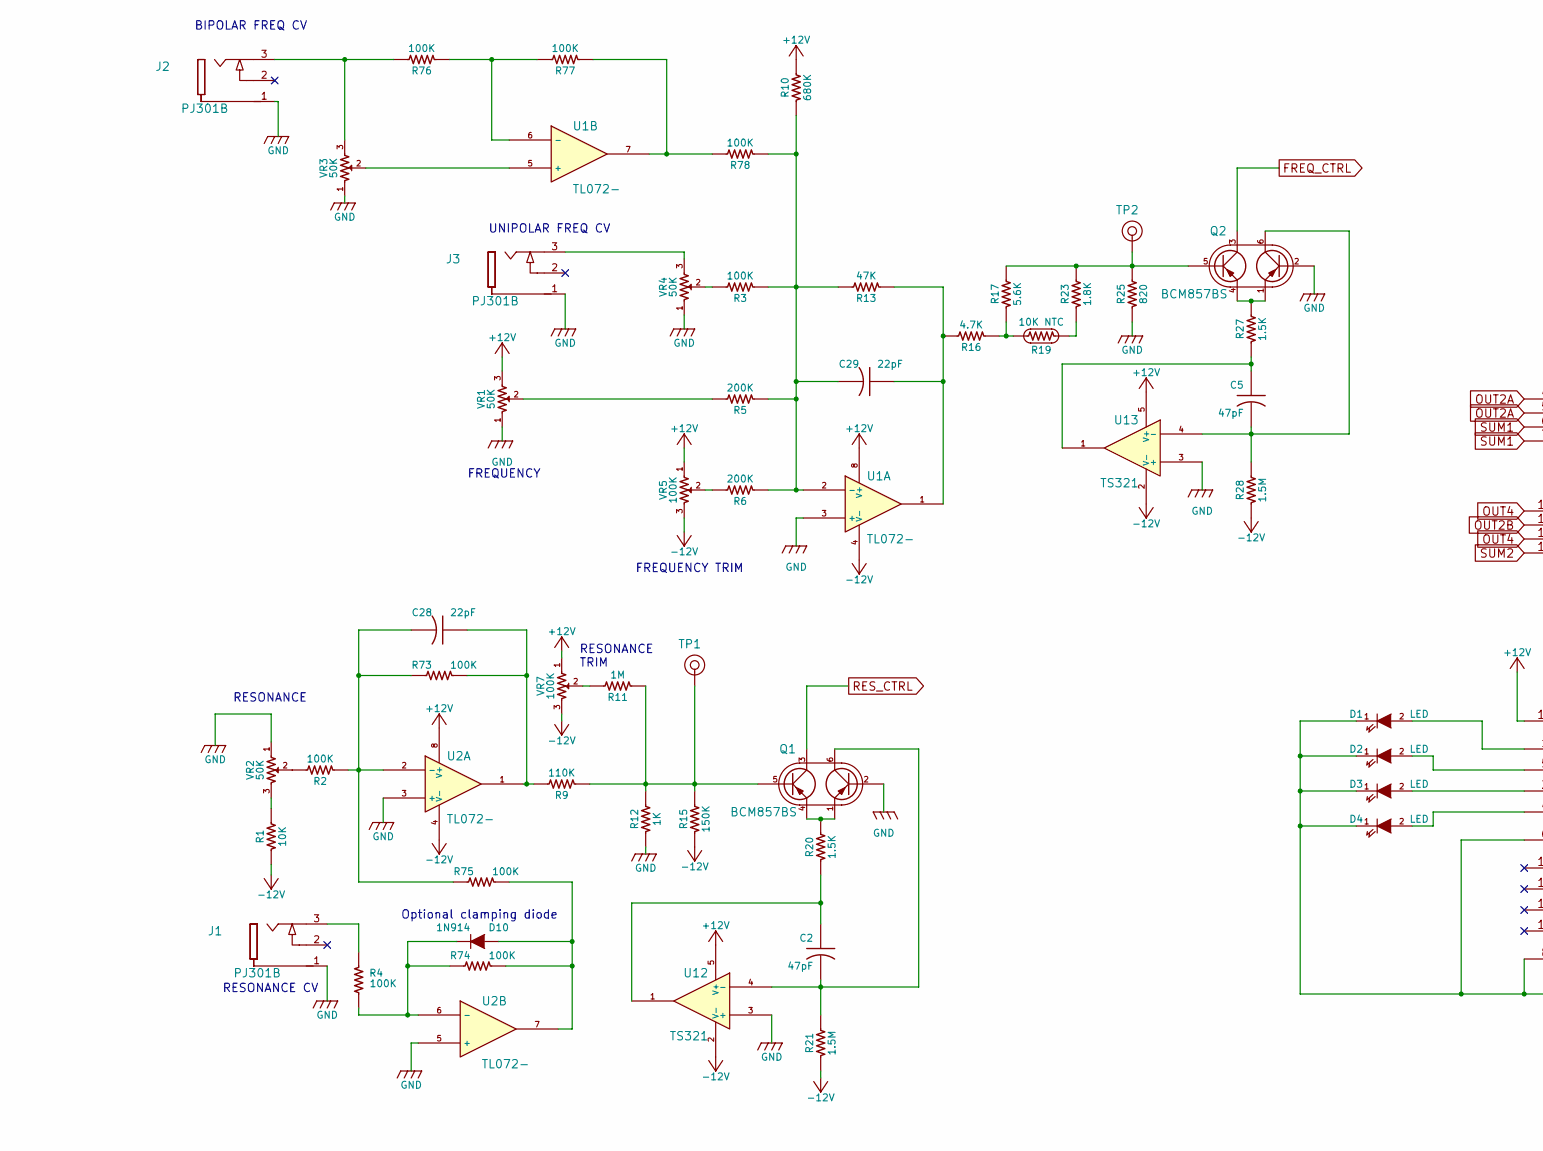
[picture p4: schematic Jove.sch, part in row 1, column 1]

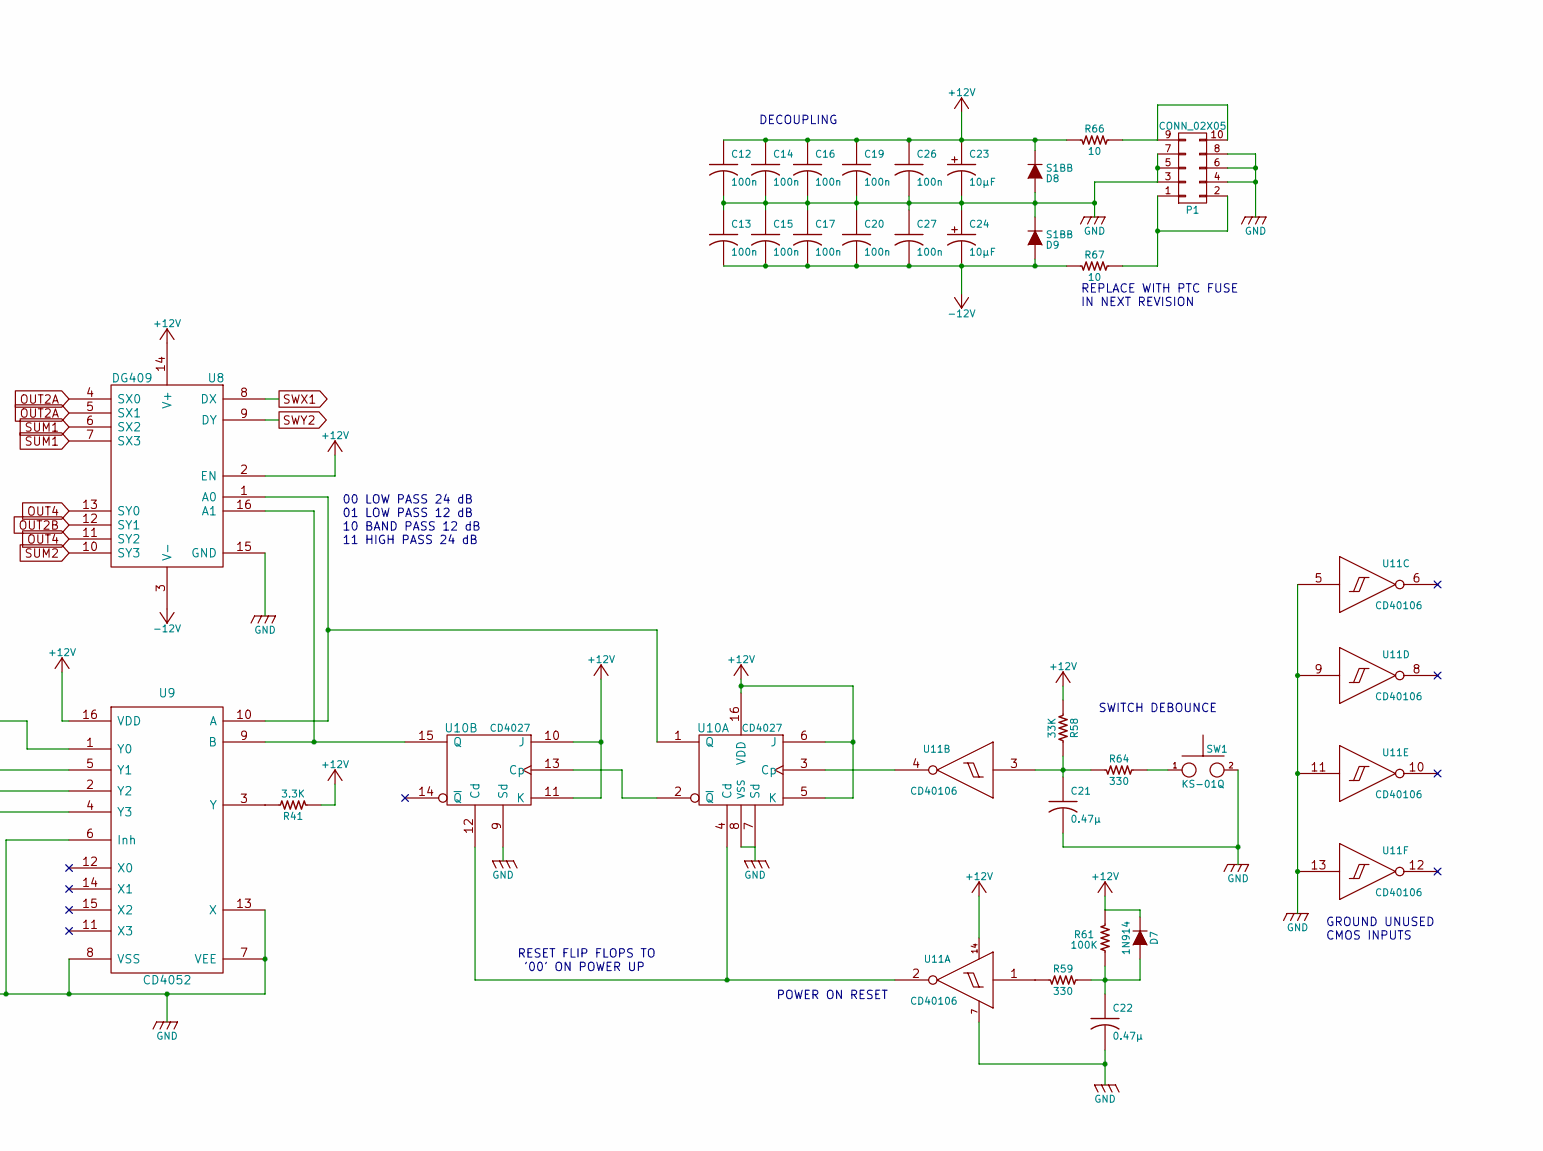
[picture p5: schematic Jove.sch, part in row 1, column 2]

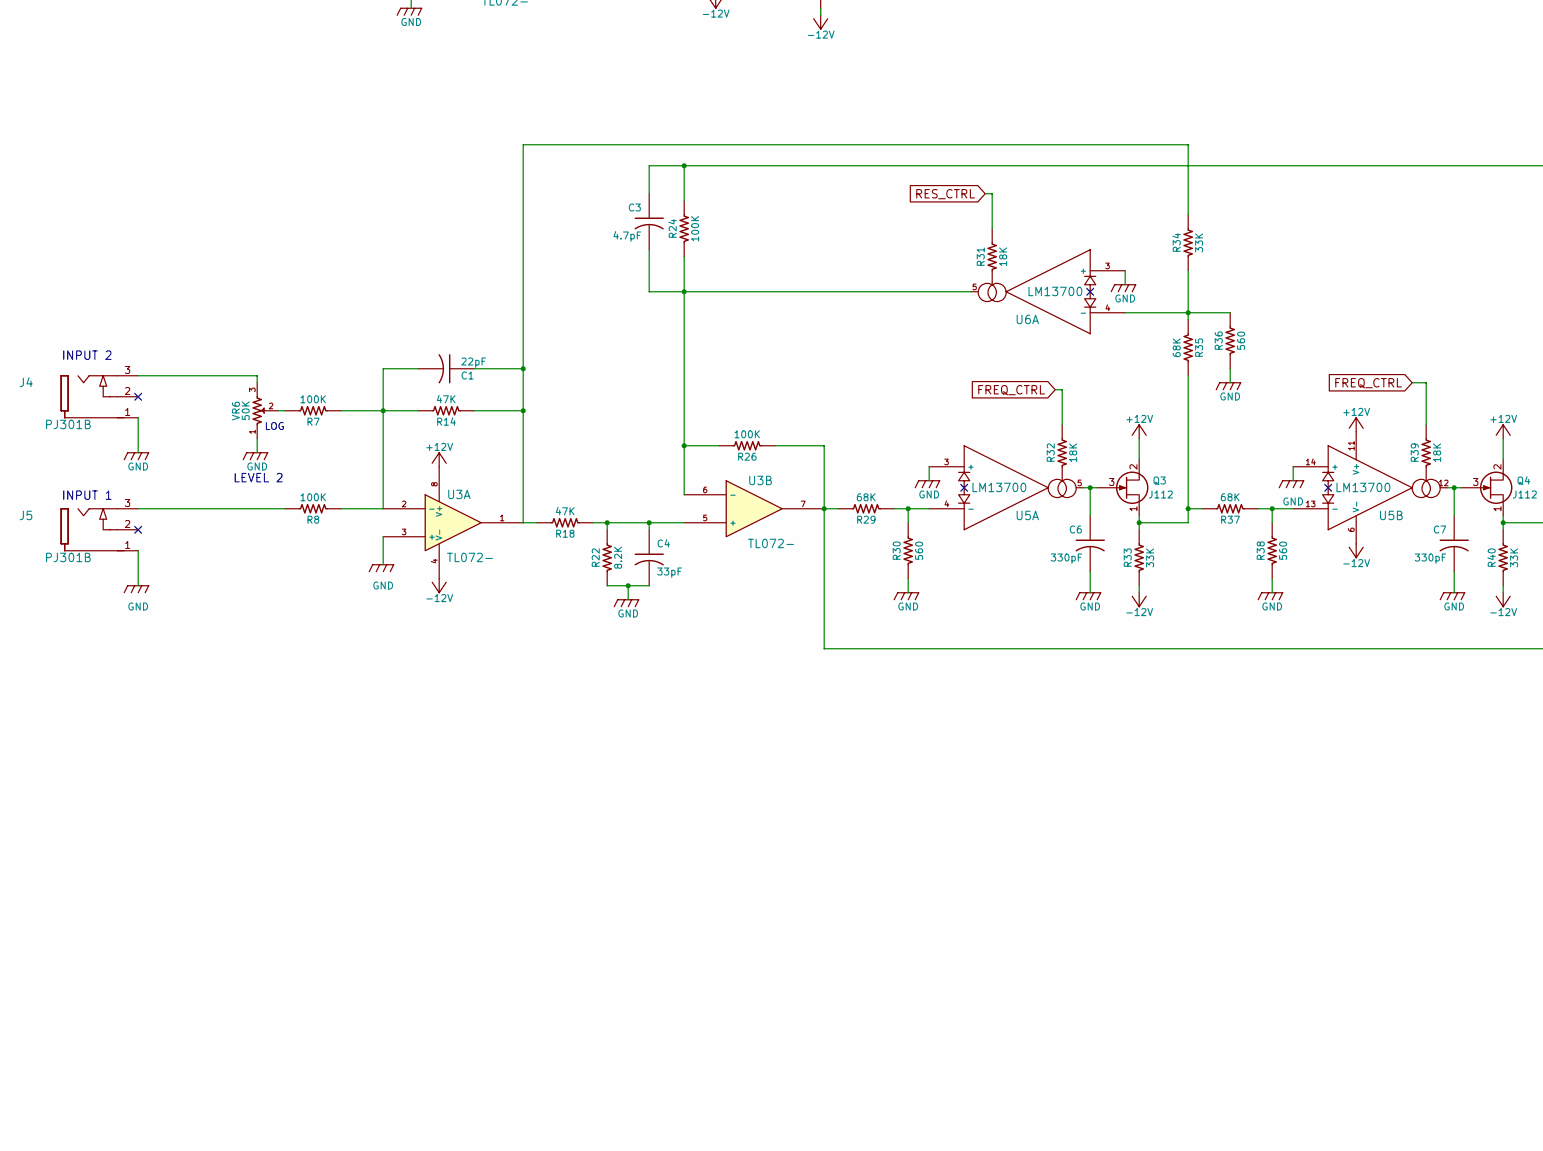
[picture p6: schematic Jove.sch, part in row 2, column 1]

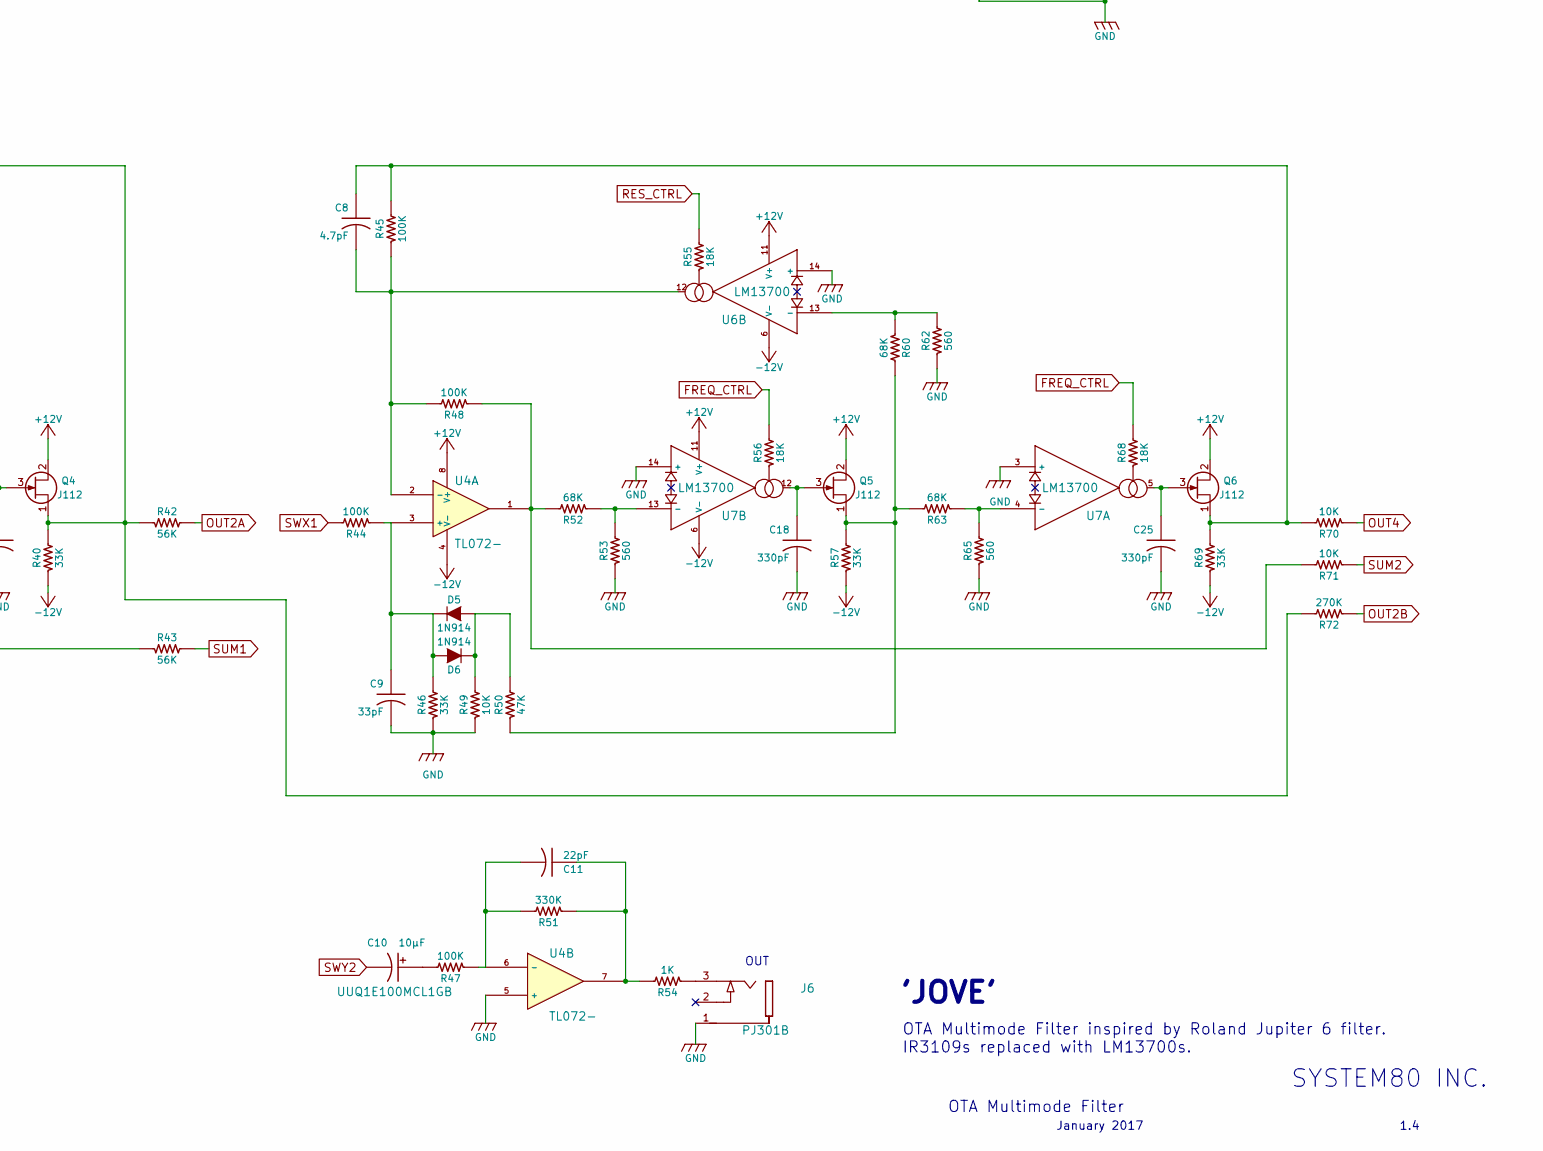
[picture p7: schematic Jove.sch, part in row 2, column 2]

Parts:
C1, C11, C28, C29: 22pF; SM0603-C-JRL
C2, C5: 47pF; SM0603-C-JRL
C3, C8: 4.7pF; SM0603-C-JRL
C4, C9: 33pF; SM0603-C-JRL
C6, C7, C18, C25: 330pF; CAP-BOX-PFR-5MM
C10: 10μF; c_elec_5x5.3; Part Number UUQ1E100MCL1GB
C12, C13, C14, C15, C16, C17, C19, C20, C26, C27: 100n; SM0603-C-JRL
C21, C22: 0.47μ; SM0603-C-JRL
C23, C24: 10μF; c_elec_5x5.3; Part Number UWJ1E100MCL1GB
D1, D2, D3, D4: LED; 3MM-LED-C1A2
D5, D6, D7, D10: 1N914; SOD323-C1A2
D8, D9: S1BB; SMB-1C2A
J1, J2, J3, J4, J5, J6: PJ301B; PJ-301B-JACK-SLOTS
P1: CONN_02X05; Pin_Header_Straight_2x05
Q1, Q2: BCM857BS; sot323-6
Q3, Q4, Q5, Q6: J112; SOT23-JRL
R1, R49, R70, R71: 10K; SM0603-R-JRL
R2, R3, R4, R7, R8, R24, R26, R44, R45, R47, R48, R61, R73, R74, R75, R76, R77, R78: 100K; SM0603-R-JRL
R5, R6: 200K; SM0603-R-JRL
R9: 110K; SM0603-R-JRL
R10: 680K; SM0603-R-JRL
R11: 1M; SM0603-R-JRL
R12, R54: 1K; SM0603-R-JRL
R13, R14, R18, R50: 47K; SM0603-R-JRL
R15: 150K; SM0603-R-JRL
R16: 4.7K; SM0603-R-JRL
R17: 5.6K; SM0603-R-JRL
R19: 10K NTC; SM0805-HAND
R20, R27: 1.5K; SM0603-R-JRL
R21, R28: 1.5M; SM0603-R-JRL
R22: 8.2K; SM0603-R-JRL
R23: 1.8K; SM0603-R-JRL
R25: 820; SM0603-R-JRL
R29, R35, R37, R52, R60, R63: 68K; SM0603-R-JRL
R30, R36, R38, R53, R62, R65: 560; SM0603-R-JRL
R31, R32, R39, R55, R56, R68: 18K; SM0603-R-JRL
R33, R34, R40, R46, R57, R58, R69: 33K; SM0603-R-JRL
R41: 3.3K; SM0603-R-JRL
R42, R43: 56K; SM0603-R-JRL
R51: 330K; SM0603-R-JRL
R59, R64: 330; SM0603-R-JRL
R66, R67: 10; SM0805-HAND
R72: 270K; SM0603-R-JRL
SW1: KS-01Q; KS-01Q-02-JRL
TP1, TP2: TEST_POINT; TEST POINT
U1, U2, U3, U4: TL072-; TSSOP8-JRL
U5, U6, U7: LM13700; SO16-JRL
U8: DG409; SO16-JRL
U9: CD4052; TSSOP-16_4.4x5mm_Pitch0.65mm
U10: CD4027; TSSOP-16_4.4x5mm_Pitch0.65mm
U11: CD40106; TSSOP-14_4.4x5mm_Pitch0.65mm
U12, U13: TS321; SOT-23-5
VR1, VR2, VR3, VR4, VR6: 50K; RV16A-41-JRL
VR5, VR7: 100K; TC33X-2

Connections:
+12V: C12.1, C14.1, C16.1, C19.1, C23.1 (+), C26.1, D7.1 (K), D8.1 (K), Q3.2 (D), Q4.2 (D), Q5.2 (D), Q6.2 (D), R10.2, R41.1, R58.2, R61.2, R66.1, U1.8 (V+), U2.8 (V+), U3.8 (V+), U4.8 (V+), U5.11 (V+), U6.11 (V+), U7.11 (V+), U8.2 (EN), U8.14 (V+), U9.16 (VDD), U10.5 (K), U10.6 (J), U10.10 (J), U10.11 (K), U10.16 (VDD), U11.14 (VDD), U12.5 (V+), U13.5 (V+), VR1.3, VR5.1, VR7.1
-12V: C13.2, C15.2, C17.2, C20.2, C24.2 (-), C27.2, D9.2 (A), R1.2, R15.2, R21.2, R28.2, R33.1, R40.1, R57.1, R67.1, R69.1, U1.4 (V-), U2.4 (V-), U3.4 (V-), U4.4 (V-), U5.6 (V-), U6.6 (V-), U7.6 (V-), U8.3 (V-), U12.2 (V-), U13.2 (V-), VR5.3, VR7.3
FREQ_CTRL: Q2.3 (C2), R32.2, R39.2, R56.2, R68.2
GND: C4.2, C6.2, C7.2, C9.2, C12.2, C13.1, C14.2, C15.1, C16.2, C17.1, C18.2, C19.2, C20.1, C21.2, C22.2, C23.2 (-), C24.1 (+), C25.2, C26.2, C27.1, D1.1 (K), D2.1 (K), D3.1 (K), D4.1 (K), D8.2 (A), D9.1 (K), J1.1, J2.1, J3.1, J4.1, J5.1, J6.1, P1.3, P1.4, P1.5, P1.6, P1.7, P1.8, Q1.2 (B1), Q2.2 (B1), R12.2, R22.1, R25.1, R30.1, R36.1, R38.1, R46.1, R49.1, R53.1, R62.1, R65.1, SW1.2, U1.3 (+), U2.3 (+), U2.5 (+), U3.3 (+), U4.5 (+), U5.3 (+), U5.14 (+), U6.3 (+), U6.14 (+), U7.3 (+), U7.14 (+), U8.15 (GND), U9.6 (Inh), U9.7 (VEE), U9.8 (VSS), U9.13 (X), U10.7 (Sd), U10.8 (VSS), U10.9 (Sd), U11.5 (In), U11.7 (VSS), U11.9 (In), U11.11 (In), U11.13 (In), U12.3 (+), U13.3 (+), VR1.1, VR2.1, VR3.1, VR4.1, VR6.1
unnamed: C1.1, R14.1, R18.2, R34.2, U3.1
unnamed: C1.2, R7.1, R8.1, R14.2, U3.2 (-)
unnamed: C2.1, R20.2, U12.1
unnamed: C2.2, Q1.6 (C1), R21.1, U12.4 (-)
unnamed: C3.1, Q4.1 (S), R24.2, R40.2, R42.2, R72.2
unnamed: C3.2, R24.1, R26.2, U3.6 (-), U6.5
unnamed: C4.1, R18.1, R22.2, U3.5 (+)
unnamed: C5.1, R27.2, U13.1
unnamed: C5.2, Q2.6 (C1), R28.1, U13.4 (-)
unnamed: C6.1, Q3.3 (G), U5.5
unnamed: C7.1, Q4.3 (G), U5.12
unnamed: C8.1, Q6.1 (S), R45.2, R69.2, R70.2
unnamed: C8.2, R45.1, R48.2, U4.2 (-), U6.12
unnamed: C9.1, D5.1 (K), D6.2 (A), R44.1, R46.2, U4.3 (+)
unnamed: C10.1 (+), R47.2
unnamed: C11.1, R51.1, R54.2, U4.7
unnamed: C11.2, R47.1, R51.2, U4.6 (-)
unnamed: C18.1, Q5.3 (G), U7.12
unnamed: C21.1, R58.1, R64.1, U11.3 (In)
unnamed: C22.1, D7.2 (A), R59.2, R61.1
unnamed: C25.1, Q6.3 (G), U7.5
unnamed: C28.1, R9.2, R73.1, U2.1
unnamed: C28.2, R2.1, R73.2, R75.2, U2.2 (-)
unnamed: C29.1, R13.1, R16.2, U1.1
unnamed: C29.2, R3.1, R5.1, R6.1, R10.1, R13.2, R78.1, U1.2 (-)
unnamed: D1.2 (A), U9.1 (Y0)
unnamed: D2.2 (A), U9.5 (Y1)
unnamed: D3.2 (A), U9.2 (Y2)
unnamed: D4.2 (A), U9.4 (Y3)
unnamed: D5.2 (A), D6.1 (K), R49.2, R50.2
unnamed: D10.1 (K), R4.1, R74.2, U2.6 (-)
unnamed: D10.2 (A), R74.1, R75.1, U2.7
unnamed: J1.3, R4.2
unnamed: J2.3, R76.2, VR3.3
unnamed: J3.3, VR4.3
unnamed: J4.3, VR6.3
unnamed: J5.3, R8.2
unnamed: J6.3, R54.1
unnamed: P1.1, P1.2, R67.2
unnamed: P1.9, P1.10, R66.2
unnamed: Q1.1 (E1), Q1.4 (E2), R20.1
unnamed: Q1.5 (B2), R9.1, R11.1, R12.1, R15.1, TP1.1
unnamed: Q2.1 (E1), Q2.4 (E2), R27.1
unnamed: Q2.5 (B2), R17.2, R23.2, R25.2, TP2.1
unnamed: Q3.1 (S), R33.2, R35.2, R37.2
unnamed: Q5.1 (S), R50.1, R57.2, R60.2, R63.2
unnamed: R1.1, VR2.3
unnamed: R2.2, VR2.2
unnamed: R3.2, VR4.2
unnamed: R5.2, VR1.2
unnamed: R6.2, VR5.2
unnamed: R7.2, VR6.2
unnamed: R11.2, VR7.2
unnamed: R16.1, R17.1, R19.2
unnamed: R19.1, R23.1
unnamed: R26.1, R29.2, R43.2, U3.7
unnamed: R29.1, R30.2, U5.4 (-)
unnamed: R31.1, U6.1
unnamed: R32.1, U5.1
unnamed: R34.1, R35.1, R36.2, U6.4 (-)
unnamed: R37.1, R38.2, U5.13 (-)
unnamed: R39.1, U5.16
unnamed: R41.2, U9.3 (Y)
unnamed: R48.1, R52.2, R71.2, U4.1
unnamed: R52.1, R53.2, U7.13 (-)
unnamed: R55.1, U6.16
unnamed: R56.1, U7.16
unnamed: R59.1, U11.1 (In)
unnamed: R60.1, R62.2, U6.13 (-)
unnamed: R63.1, R65.2, U7.4 (-)
unnamed: R64.2, SW1.1
unnamed: R68.1, U7.1
unnamed: R76.1, R77.2, U1.6 (-)
unnamed: R77.1, R78.2, U1.7
unnamed: U1.5 (+), VR3.2
unnamed: U8.1 (A0), U9.10 (A), U10.1 (Q)
unnamed: U10.3 (Cp), U11.4 (Out)
unnamed: U10.4 (Cd), U10.12 (Cd), U11.2 (Out)
unnamed: U10.2 (~Q), U10.13 (Cp)
unnamed: U8.16 (A1), U9.9 (B), U10.15 (Q)
OUT2A: R42.1, U8.4 (SX0), U8.5 (SX1)
OUT2B: R72.1, U8.12 (SY1)
OUT4: R70.1, U8.11 (SY2), U8.13 (SY0)
RES_CTRL: Q1.3 (C2), R31.2, R55.2
SUM1: R43.1, U8.6 (SX2), U8.7 (SX3)
SUM2: R71.1, U8.10 (SY3)
SWX1: R44.2, U8.8 (DX)
SWY2: C10.2 (-), U8.9 (DY)

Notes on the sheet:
00 LOW PASS 24 dB 01 LOW PASS 12 dB 10 BAND PASS 12 dB 11 HIGH PASS 24 dB
POWER ON RESET
SWITCH DEBOUNCE
DECOUPLING
GROUND UNUSED CMOS INPUTS
RESET FLIP FLOPS TO '00' ON POWER UP
LOG
FREQUENCY TRIM
FREQUENCY
RESONANCE
BIPOLAR FREQ CV
RESONANCE CV
RESONANCE TRIM
UNIPOLAR FREQ CV
Optional clamping diode
INPUT 2
LEVEL 2
INPUT 1
OTA Multimode Filter
1.4
OUT
January 2017
OTA Multimode Filter inspired by Roland Jupiter 6 filter. IR3109s replaced with LM13700s.
'JOVE'
SYSTEM80 INC.
REPLACE WITH PTC FUSE IN NEXT REVISION

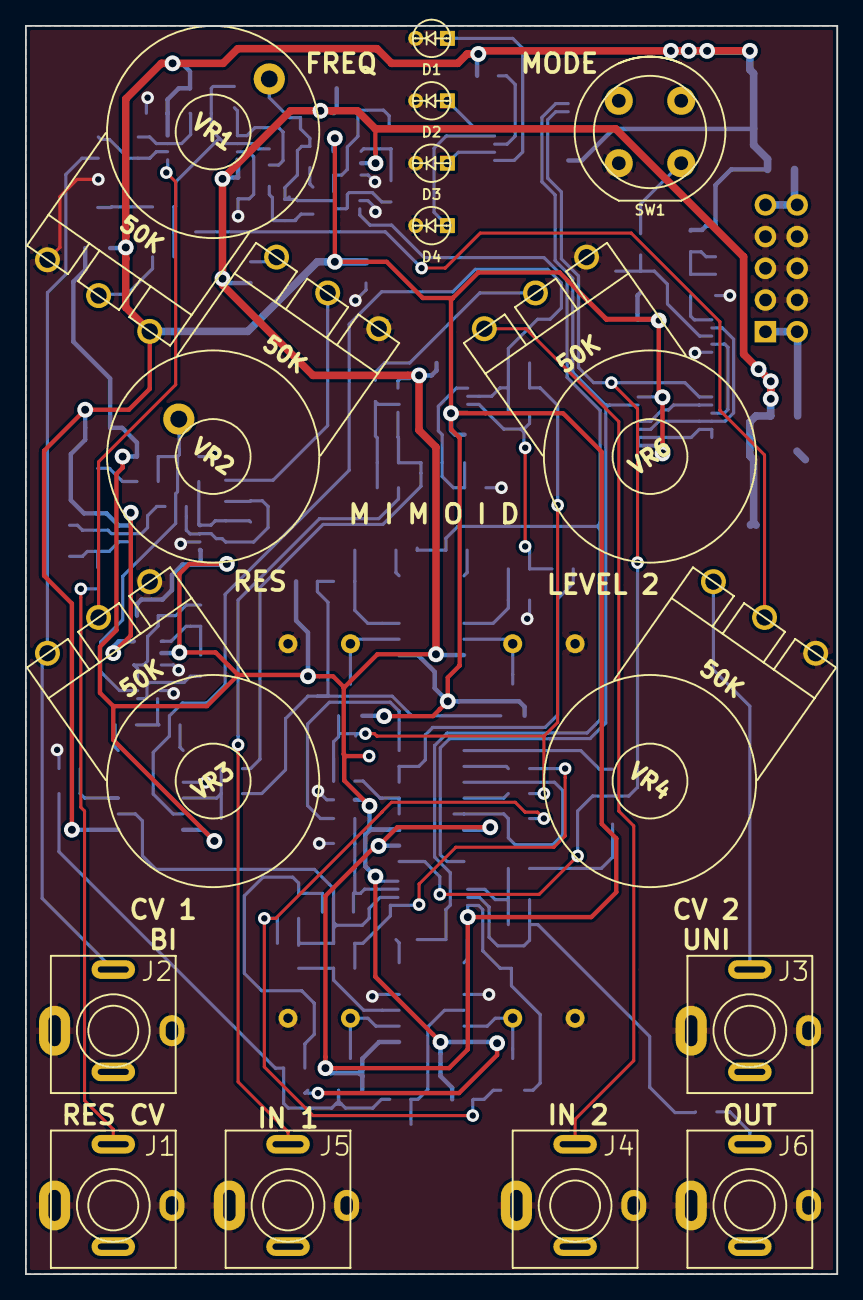
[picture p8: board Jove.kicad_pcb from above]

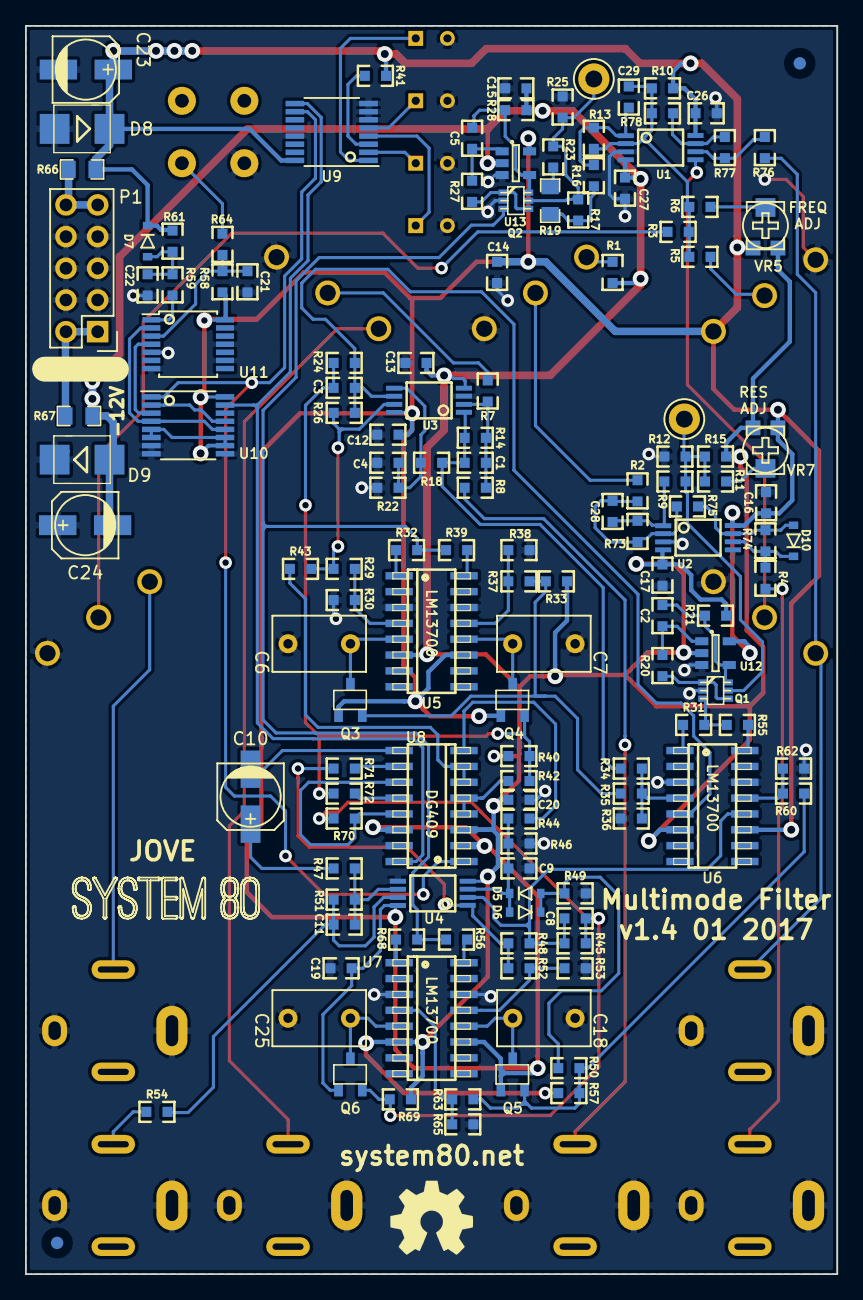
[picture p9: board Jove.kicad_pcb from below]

Board: 2 copper layers, 65.0 x 100.0 mm, 153 parts (137 on the bottom side), 92 nets.

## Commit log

2015-04-27 first commit. Note that this project uses Kicad BZR 5624
    [Eurorack-JP6-filter.sch]
2015-04-27 schematic capture almost finished
    [Eurorack-JP6-filter.sch]
2015-04-28 schematic capture almost done. Power on Reset circuit breadboarded and implemented in schematic
    [Eurorack-JP6-filter.sch]
2015-04-28 capture done, still need to doublecheck and annotate, then do footprint association
    [Eurorack-JP6-filter.sch]
2015-04-28 annotation done, export netlist and start footprint assignment
    [Eurorack-JP6-filter.sch]
2015-04-29 footprints assigned, about to start layout
    [Eurorack-JP6-filter.sch]
2015-04-29 started placing components, pots, jacks, sw1 and LEDs placed
    [$Eurorack-JP6-filter.sch, Eurorack-JP6-filter.kicad_pcb]
2015-04-30 placing components, a few footprints updated
    [$Eurorack-JP6-filter.sch, Eurorack-JP6-filter.kicad_pcb, Eurorack-JP6-filter.sch]
2015-05-01 components placed, beginning to route. current version crashes when 3D viewer is launched, going to try to open in previous version
    [$Eurorack-JP6-filter.sch, Eurorack-JP6-filter.kicad_pcb, Eurorack-JP6-filter.sch]
2015-05-02 routed most signals, still need to route power and ground
    [Eurorack-JP6-filter.kicad_pcb]
2015-05-03 routing power, swapped units on hex inverter
    [Eurorack-JP6-filter.kicad_pcb, Eurorack-JP6-filter.sch]
2015-05-03 still routing
    [Eurorack-JP6-filter.kicad_pcb]
2015-05-03 8 connections left to route
    [Eurorack-JP6-filter.kicad_pcb]
2015-05-03 routed, could still use refining
    [Eurorack-JP6-filter.kicad_pcb]
2015-05-05 finished routing, mostly cleaned upk, parts modelled in 5365
    [Eurorack-JP6-filter.kicad_pcb, Eurorack-JP6-filter.sch]
2015-05-05 minor tweaking of positive power bus
    [Eurorack-JP6-filter.kicad_pcb]
2015-05-05 adjusted silkscreen
    [Eurorack-JP6-filter.kicad_pcb]
2015-05-07 done touching up. doublecheck IC pin outs and do footprint check
    [Eurorack-JP6-filter.kicad_pcb]
2015-05-07 gerbers plotted for footprint testing, still need to check digital IC pinouts
    [Eurorack-JP6-filter-B_Cu.gbr, Eurorack-JP6-filter-B_Mask.gbr, Eurorack-JP6-filter-B_SilkS.gbr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]
2015-05-07 anode cathode diode swap from latest kicad library updates fixed, ground plane tweaking
    [Eurorack-JP6-filter.kicad_pcb, Eurorack-JP6-filter.sch]
2015-05-10 PCB ordered from dirtypcbs.com on May 9
    [Eurorack JP6 SVF 14HP drill holes.dxf, Eurorack-JP6-filter-Edge_Cuts.dxf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]
2015-07-27 commit before changing JFET buffer resistor error
    [Eurorack-JP6-filter.kicad_pcb]
2015-07-27 JFET buffer 33K R to GND error fixed to -12V
    [Eurorack-JP6-filter.kicad_pcb, Eurorack-JP6-filter.sch]
2016-03-08 clean up duplicate versions of Gerbers, add Panel folder for panel fab and screen graphics
    [Eurorack JP6 SVF 14HP drill holes.dxf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]
2016-03-08 stray .dxf cleanup and update readme and license
    [Eurorack JP6 SVF 14HP drill holes.dxf, Eurorack-JP6-filter-Edge_Cuts.dxf, Eurorack-JP6-filter-F_SilkS.dxf]
2016-03-08 plot pdf schematic
2016-03-14 eps for screen printing added
2016-03-16 changed power-on-reset R61 resistor to 100K for more reliable POR
    [Eurorack-JP6-filter.sch]
2016-03-29 cleaned up missing schematic libraries, added link in README.md to project specific library
    [Eurorack-JP6-filter.sch]
2016-04-29 Power polarity protection diodes added, TSSOP-8 footprints changed to KiCad standard, removal of references to VRML1 models, Gerber plots updated
    [Eurorack-JP6-filter-B_Cu.gbl, Eurorack-JP6-filter-B_Mask.gbs, Eurorack-JP6-filter-B_SilkS.gbo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]
2016-10-19 changed CV2 intput to attenuverter
    [Eurorack-JP6-filter.kicad_pcb, Eurorack-JP6-filter.sch]
2016-10-19 added resonance CV input
    [Eurorack-JP6-filter.sch]
2016-10-20 needed to ad inverting stage to resonance jack input so more positive CV = more resonance. Question: is diode clamp required on resonance CV jack input?
    [Eurorack-JP6-filter.sch]
2016-10-20 replaced op amp servo in exponetial converters with TS321
    [Eurorack-JP6-filter.sch]
2016-10-21 schematic edited, changes simulated. ready to change layout
    [Eurorack-JP6-filter.kicad_pcb, Eurorack-JP6-filter.sch]
2016-10-21 annoated additional components and passed ERC
    [Eurorack-JP6-filter.sch]
2016-10-23 hacking together v1.3 pcb
    [Eurorack-JP6-filter.kicad_pcb, Eurorack-JP6-filter.sch]
2016-10-23 v1.3 routed
    [Eurorack-JP6-filter.kicad_pcb, Eurorack-JP6-filter.sch]
2016-10-23 routed and DRC passed, silkscreen edited
    [Eurorack-JP6-filter.kicad_pcb]
2016-10-24 fixed cretnious things only a cretin would do
    [Eurorack-JP6-filter.kicad_pcb, Eurorack-JP6-filter.sch]
2016-10-24 cleaned up silkscreen a bit. ready to do panel alignment test
    [Eurorack-JP6-filter.kicad_pcb]
2016-10-24 Gerbers generated and checked
    [Eurorack-JP6-filter-B.Cu.gbl, Eurorack-JP6-filter-B.Mask.gbs, Eurorack-JP6-filter-B.SilkS.gbo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]
2016-10-24 fixed the cretinous error made by a cretin by which TS321 rails were reversed because said cretin can't pay attention to detail. Also added small pF caps in feedback of freq and res CV input stages
    [Eurorack-JP6-filter.kicad_pcb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]
2016-11-11 removed centre trimmer, doesn't seem to be required
    [Eurorack-JP6-filter.kicad_pcb, Eurorack-JP6-filter.sch]
2016-11-22 generated BOM
    [Eurorack-JP6-filter.csv, Eurorack-JP6-filter.kicad_pcb, Eurorack-JP6-filter.sch]
2016-11-22 rename project files to Jove
    [Jove.csv, Jove.kicad_pcb, Jove.sch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]
2016-11-22 updated rescue library references to new project name
    [Jove.sch]
2016-12-03 commit before making panel branch
    [Jove.kicad_pcb]
2016-12-28 updated 0603 footprints to square pads to please assembler, added logo, tweaked main rail traces
    [Jove.kicad_pcb]
2017-01-04 genereated gerbers for panelization by PCB house
    [Jove.kicad_pcb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]
2017-02-16 corrected D6/D7 reference swap on PCB. Started working on manual
    [Jove.csv, Jove.kicad_pcb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]
2017-04-06 changed R51 and R72 values to incrase overall output gain and bring down LP12 output levels to match other modes
    [Jove.kicad_pcb, Jove.sch]
2017-05-27 updated BOM, readme, added octopart link
    [JOVE_BOM.csv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]
2017-05-27 updated R72 and R51 in BOM
    [JOVE_BOM.csv]
2017-11-15 updated manual, updated jove.pdf schematic to v1.4
